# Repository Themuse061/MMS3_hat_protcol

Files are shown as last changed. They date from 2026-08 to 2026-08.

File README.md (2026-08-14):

# MMS3 Hat Protocol
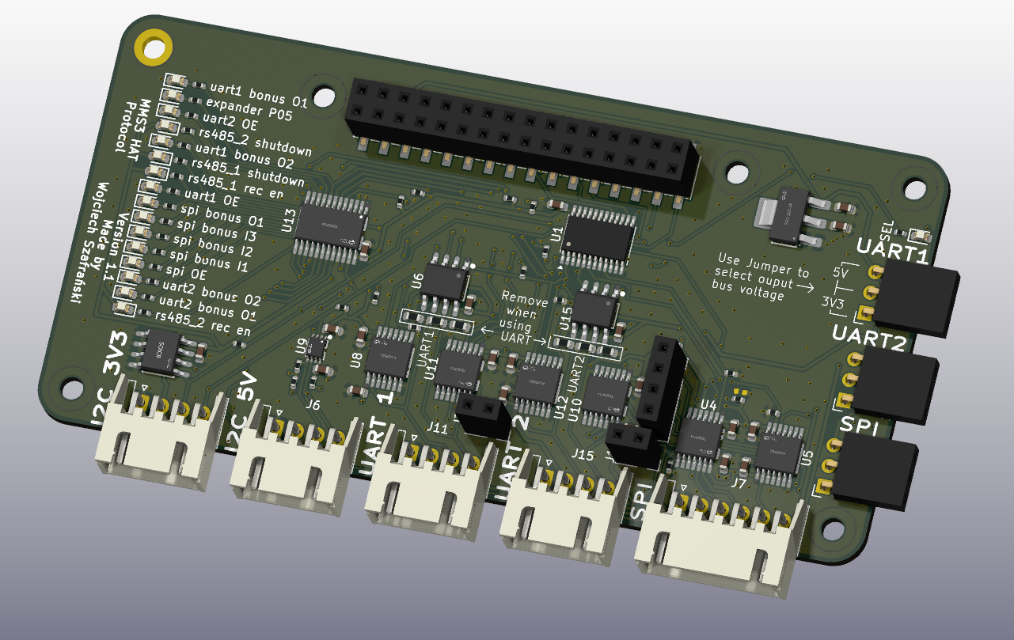
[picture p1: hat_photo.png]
zdjęcie

## Sekcja 1: Dokumentacja Hat'a

### Krótki opis projektu
Moduł rozszerzeń protokołów komunikacyjnych dla standardu ChainBus. Hat umożliwia podłączanie urządzeń zewnętrznych komunikujących się za pomocą interfejsów UART, RS485, I2C oraz SPI.

Umożliwia  zmianę napięć logicznych (3.3V lub 5V) osobno dla każdej sekcji, a linie komunikacyjne są domyślnie odłączone przy starcie systemu.

### Zgodność ze standardem ChainBus

* ✅  Używa złącza ChainBus, nie zmienia jego miejsca ani pinoutu.
* ✅  Używa wyłącznie interfejsów I2C, SPI lub UART i nie inicjuje samodzielnie nowych transmisji (Nie jest master'em I2C albo SPI).
* ✅  Spełnia wymagania mechaniczne standardu (wymiary PCB, rozstaw otworów).
* ✅  Pobiera maksymalny prąd zgodny z ilością na jednego hat'a
* ✅  Obsługuje napięcie wejściowe BRD_VIN do wartości 48V.

### Komunikacja i adresowanie

#### Adresacja I2C
Do konfiguracji pracy buforów trójstanowych oraz transceiverów RS485 wykorzystywany jest ekspander GPIO.

| Układ (IC) | Funkcja | Adres I2C (7-bit) |
| :--- | :--- | :---: |
| **TCA9535PWR** | Ekspander GPIO (sterowanie buforami) | `0100000b` (0x20) |

Uwaga: Adresy expander'a gpio i pamięci EEPROM są zajęte na I2C wychodzącym z hat'a

---

### Konfiguracja i wybór napięć logicznych (3.3V / 5V)

Sekcje UART1, UART2 oraz SPI posiadają niezależną regulację napięcia pracy za pomocą zworek:

| Zworka  | Sekcja | Pozycja 1-2 | Pozycja 2-3 |
| :--- | :----- | :--- | :--- |
| **J8**  | UART 1 | Napięcie logiki **3.3V** | Napięcie logiki **5V** |
| **J14** | UART 2 | Napięcie logiki **3.3V** | Napięcie logiki **5V** |
| **J5**  | SPI | Napięcie logiki **3.3V** | Napięcie logiki **5V** |

---

### Pełny pinout ekspandera GPIO (TCA9535PWR)

Wszystkie magistrale (z wyjątkiem I2C) są przy starcie urządzenia **fizycznie odłączone**. Do ich aktywacji i konfiguracji służą poniższe piny ekspandera:

| Port | Nazwa sygnału | Domyślny stan sprzętowy  | Opis funkcjonalny |
| :--- | :--- | :--- | :--- |
| **P00** | `UART 1 OE` | Niski (L) - Odłączony | Aktywacja (Output Enable) bufora linii UART 1 |
| **P01** | `UART 1 RS485 RE_N` | Wysoki (H)  - Wyłączony  | Negowane wejście Receiver Enable ($\overline{RE}$) dla RS485-1 |
| **P02** | `UART 1 SHDN_N` | Wysoki (H) - Wyłączony | Negowane wejście Shutdown ($\overline{SD}$) dla RS485-1 |
| **P03** | `UART 1 BONUS OUT`  | Niski (L) | Dodatkowe wyjście pomocnicze (Bonus Out) na złączu J12 |
| **P04** | `UART 1 BONUS OUT`  | Niski (L) | Dodatkowe wyjście pomocnicze (Bonus Out) na złączu J12 |
| **P05** | `STATUS LED` | - | Dioda statusowa ogólnego przeznaczenia (LED) |
| **P06** | `UART 2 OE` | Niski (L) - Odłączony | Aktywacja (Output Enable) bufora linii UART 2 |
| **P07** | `UART 2 RS485 RE_N` | Wysoki (H) - Wyłączony | Negowane wejście Receiver Enable ($\overline{RE}$) dla RS485-2 |
| **P10** | `UART 2 SHDN_N` | Wysoki (H) - Wyłączony | Negowane wejście Shutdown ($\overline{SD}$) dla RS485-2 |
| **P11** | `UART 2 BONUS OUT`  | Niski (L) | Dodatkowe wyjście pomocnicze (Bonus Out) na złączu J13 |
| **P12** | `UART 2 BONUS OUT`  | Niski (L) | Dodatkowe wyjście pomocnicze (Bonus Out) na złączu J13 |
| **P13** | `SPI 1 ENABLE` | Niski (L) - Odłączony | Aktywacja (Output Enable) bufora linii SPI |
| **P14** | `SPI 1 BONUS IN` | — | Dodatkowe wejście pomocnicze (Bonus In) na złączu J9 |
| **P15** | `SPI 1 BONUS IN` | — | Dodatkowe wejście pomocnicze (Bonus In) na złączu J9 |
| **P16** | `SPI 1 BONUS IN` | — | Dodatkowe wejście pomocnicze (Bonus In) na złączu J9 |
| **P17** | `SPI 1 BONUS OUT` | — | Dodatkowe wyjście pomocnicze (Bonus Out) na złączu J9 |

---

### Konfiguracja trybów pracy: UART vs RS485

Linie komunikacyjne oraz złącza fizyczne są współdzielone pomiędzy standardowym interfejsem UART a różnicowym RS485. Wymaga to odpowiedniej konfiguracji sprzętowej i programowej.

#### Tryb 1: Standardowy UART
Aby używać kanału jako klasycznego interfejsu UART:
1. **Włącz magistralę:** Ustaw odpowiedni pin `UART OE` (P00 lub P06) w stan wysoki (`1`).
2. **Wylutuj rezystor terminujący:** Należy  **odlutować rezystor terminujący RS485** ($120\ \Omega$) przypisany do danego kanału (rezystory są oznaczone  na  PCB). Pozostawienie rezystora obciąży linie RX/TX, co może powodować błędy lub uszkodzenie układu.

#### Tryb 2: Interfejs RS485
Aby używać kanału w standardzie  RS485:
1. **Włącz magistralę:** Ustaw odpowiedni pin `UART OE` (P00 lub P06) w stan wysoki (`1`).
2. **Aktywuj transceiver:** Ustaw piny Receiver Enable (`RE_N`) oraz Shutdown (`SHDN_N`) w stan niski (`0`).
3. **Terminacja linii:** Rezystor terminujący na PCB powinien pozostać wlutowany .

---

### Pinout złączy zewnętrznych

#### J11 (UART1 / RS485-1) oraz J15 (UART2 / RS485-2)
Złącza te współdzielą piny fizyczne dla obu standardów komunikacji.

| Pin | Nazwa | Funkcja w trybie UART | Funkcja w trybie RS485 |
| :---- | :--- | :--- | :--- |
| **1** | `GND` | Masa sygnałowa | Masa odniesienia |
| **2** | `V_SEL`  | Wybrane zasilanie (3.3V / 5V) | Wybrane zasilanie (3.3V / 5V) |
| **3** | `A / RX` | Odbiór danych (RX) | Linia różnicowa **A** (nieodwracająca) |
| **4** | `B / TX` | Nadawanie danych (TX) | Linia różnicowa **B** (odwracająca) |

#### J4 (I2C 3.3V) oraz J6 (I2C 5V)
Złącza magistrali I2C są połączone na stałe do linii ChainBus poprzez odpowiednie translatory poziomów.
* **J4 (3.3V):** Pin 1: GND | Pin 2: 3.3V | Pin 3: SDA 3.3V | Pin 4: SCL 3.3V
* **J6 (5.0V):** Pin 1: GND | Pin 2: 5.0V | Pin 3: SDA 5.0V | Pin 4: SCL 5.0V

#### J7 (SPI)
Złącze magistrali SPI z konwersją napięć (3.3V / 5V w zależności od J5):
* Pin 1: GND | Pin 2: V_SEL | Pin 3: SCK | Pin 4: MOSI | Pin 5: MISO | Pin 6: CS

---

### Złącza pomocnicze (Bonus Pins)

Złącza te służą do wyprowadzenia dodatkowych sygnałów cyfrowych sprzężonych z buforami danej magistrali. Działają tylko wtedy, gdy bufor nadrzędnej magistrali jest włączony (`OE` = `1`).

* **J12 (UART 1):** Pin 1: `P01` (In) | Pin 2: `P02` (Out/In) | Pin 3: `P03` (Out) | Pin 4: `P04` (Out)
* **J13 (UART 2):** Pin 1: `P07` (In) | Pin 2: `P10` (Out/In) | Pin 3: `P11` (Out) | Pin 4: `P12` (Out)
* **J9 (SPI):** Pin 1: `P14` (In) | Pin 2: `P15` (In) | Pin 3: `P16` (In) | Pin 4: `P17` (Out)

---

### Gotowe arkusze hierarchiczne
W projekcie wykorzystano następujące arkusze hierarchiczne:
* **SPI tri state switch** – Moduł przełączania linii interfejsu SPI z użyciem buforów trójstanowych oraz układów konwersji poziomów napięciowych (3.3V <-> 5V).
* **UART tri state switch + RS485 converter** – Blok przełączania linii UART z dopasowaniem poziomów napięć oraz zintegrowanym transceiverem RS485 i układem sterowania przepływem danych (RE/SHDN).

---

## Sekcja 2: Specyfikacja standardu ChainBus

### Architektura i łączenie modułów
Standard ChainBus umożliwia modułowe łączenie hatów. Na jednym MMS3 można zamontować pionowo **do 8 hat'ów**. Połączenie realizowane jest poprzez wpięcie złącza męskiego kolejnego hat'a w złącze żeńskie poprzedniego.

### Komunikacja i sterowanie
Magistrala ChainBus jest w pełni cyfrowa. Płyta główna nie steruje bezpośrednio sygnałami ogólnego przeznaczenia (GPIO) na poszczególnych hat'ach. Wszelkie operacje (np. odczyt czujników, przełączanie magistral) muszą być realizowane przez dedykowane układy scalone komunikujące się przez interfejsy systemowe.

Wybór aktywnego modułu realizowany jest przez układ przełącznika magistrali (bus switch) na płycie głównej. Dzięki temu linie I2C, SPI i UART są niezależne dla każdego hat'a (brak konfliktów adresów I2C między różnymi hatami).
* **Identyfikacja:** Każdy moduł powinien posiadać pamięć EEPROM na magistrali I2C w celu identyfikacji płyty przez system - układ M24C64-W skonfigurowany na adres `1010000` przy liniach adresowych A0, A1, A2 zwartych do masy.

### Zasilanie
Złącze ChainBus dostarcza następujące linie zasilania:

| Magistrala zasilania | Napięcie znamionowe | Maksymalny prąd (łączny dla 8 hatów) | Szacowany prąd na jeden hat |
| :--- | :---: | :---: | :---: |
| **5V** | 5.0 V | 1.0 A | 125 mA |
| **12V stby** | 12.0 V | 0.5 A | 65 mA |
| **BRD_VIN** | 12.0 V – 48.0 V | 1.5 A | 185 mA |

*   Komponenty podłączone do linii `BRD_VIN` muszą być przystosowane do pracy z napięciem od 12V do **48 V**.

### Wymagania mechaniczne i złącza
* **Wymiary PCB:** Niedozwolona jest zmiana obrysu płytki oraz położenia otworów montażowych, aby zachować kompatybilność mechaniczną.
* **Pozycjonowanie złączy ChainBus:** Położenie złącza standardu 2x16 SMD (raster 2.54 mm) musi być zgodne z szablonem. Złącze żeńskie montowane jest na stronie FRONT, natomiast złącze męskie na stronie BACK.
* **Komponenty:** Wszystkie komponenty powinny znajdować się na stronie FRONT płytki, aby uniknąć kolizji mechanicznych z elementami sąsiadujących modułów w stosie.

---

## Sekcja 3: Licencje

### Licencje projektu

*   **PCB:** CERN-OHL-P
*   **Software:** MIT License

[Template](https://github.com/KoNaR-Hefajstos/MMS3_hat_templates/) jest na licencji CC0 1.0 Universal. **Reszta projektu nie jest na tej licencji**

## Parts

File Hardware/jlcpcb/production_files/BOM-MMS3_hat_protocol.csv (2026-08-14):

Comment | Designator | Footprint | LCSC | Quantity
100nF | C1,C10,C11,C12,C13,C14,C15,C17,C18,C19,C2,C20,C21,C22,C4,C6,C7,C8,C9 | C_0603 | C14663 | 19
10kΩ | R10,R11,R15,R16,R17,R18,R19,R2,R20,R22,R3,R38,R40,R42,R44,R6,R8,R9 | R_0402 | C25744 | 18
10uF | C3,C5 | C_0603 | C19702 | 2
120Ω | R25,R28 | R_0603 | C22787 | 2
200kΩ | R7 | R_0402 | C25764 | 1
330Ω | R12,R13,R14,R21,R37,R39,R41,R43,R45,R46,R47,R48,R49,R5,R50,R51,R52 | R_0402 | C25104 | 17
510Ω | R23,R24,R26,R27 | R_0603 | C23193 | 4
AMS1117 | U3 | SOT-223-3_L6.5-W3.4-P2.30-LS7.0-BR | C6186 | 1
M24C64 | U2 | SOIC-8_L5.0-W4.0-P1.27-LS6.0-BL | C79988 | 1
MAX13487EESA | U15,U6 | SOIC-8_L4.9-W3.9-P1.27-LS6.0-BL | C18347 | 2
PCA9306DCUR | U9 | SSOP-8_L2.0-W2.3-P0.50-LS3.1-BR | C33196 | 1
Red | D10,D15,D16,D17,D18,D19,D20,D21,D22,D23,D24,D25,D26,D6,D7,D8,D9 | D_0603 | C2286 | 17
SN74CB3Q3384APW | U1 | TSSOP-24_4.4x7.8mm_P0.65mm | C469874 | 1
TCA9535PWR_C130204 | U13 | TSSOP-24_L7.8-W4.4-P0.65-LS6.4-BL | C130204 | 1
TXU0104PWR | U10,U11,U12,U4,U5,U8 | TSSOP-14_L5.0-W4.4-P0.65-LS6.4-BL | C2938871 | 6
Conn_01x02_Pin | J10 | PinSocket_1x02_P2.54mm_Vertical |  | 1
Conn_01x04_Pin | J9 | PinSocket_1x04_P2.54mm_Vertical |  | 1
Chainbus Out | J2 | PinSocket_2x16_P2.54mm_Vertical_SMD |  | 1
Conn_01x03_Pin | J5 | PinSocket_1x03_P2.54mm_Horizontal |  | 1
Conn_01x02_Pin | J3 | PinSocket_1x02_P2.54mm_Vertical |  | 1
Conn_01x04_Pin | J15 | JST_XH_S4B-XH-A_1x04_P2.50mm_Horizontal |  | 1
Conn_01x03_Pin | J14 | PinSocket_1x03_P2.54mm_Horizontal |  | 1
Conn_01x04_Pin | J11 | JST_XH_S4B-XH-A_1x04_P2.50mm_Horizontal |  | 1
Conn_01x03_Pin | J8 | PinSocket_1x03_P2.54mm_Horizontal |  | 1
Conn_01x04_Pin | J4 | JST_XH_S4B-XH-A_1x04_P2.50mm_Horizontal |  | 1
Conn_01x06_Pin | J7 | JST_XH_S6B-XH-A_1x06_P2.50mm_Horizontal |  | 1
Conn_01x04_Pin | J6 | JST_XH_S4B-XH-A_1x04_P2.50mm_Horizontal |  | 1
Chainbus in | J1 | PinHeader_2x16_P2.54mm_Vertical_SMD |  | 1

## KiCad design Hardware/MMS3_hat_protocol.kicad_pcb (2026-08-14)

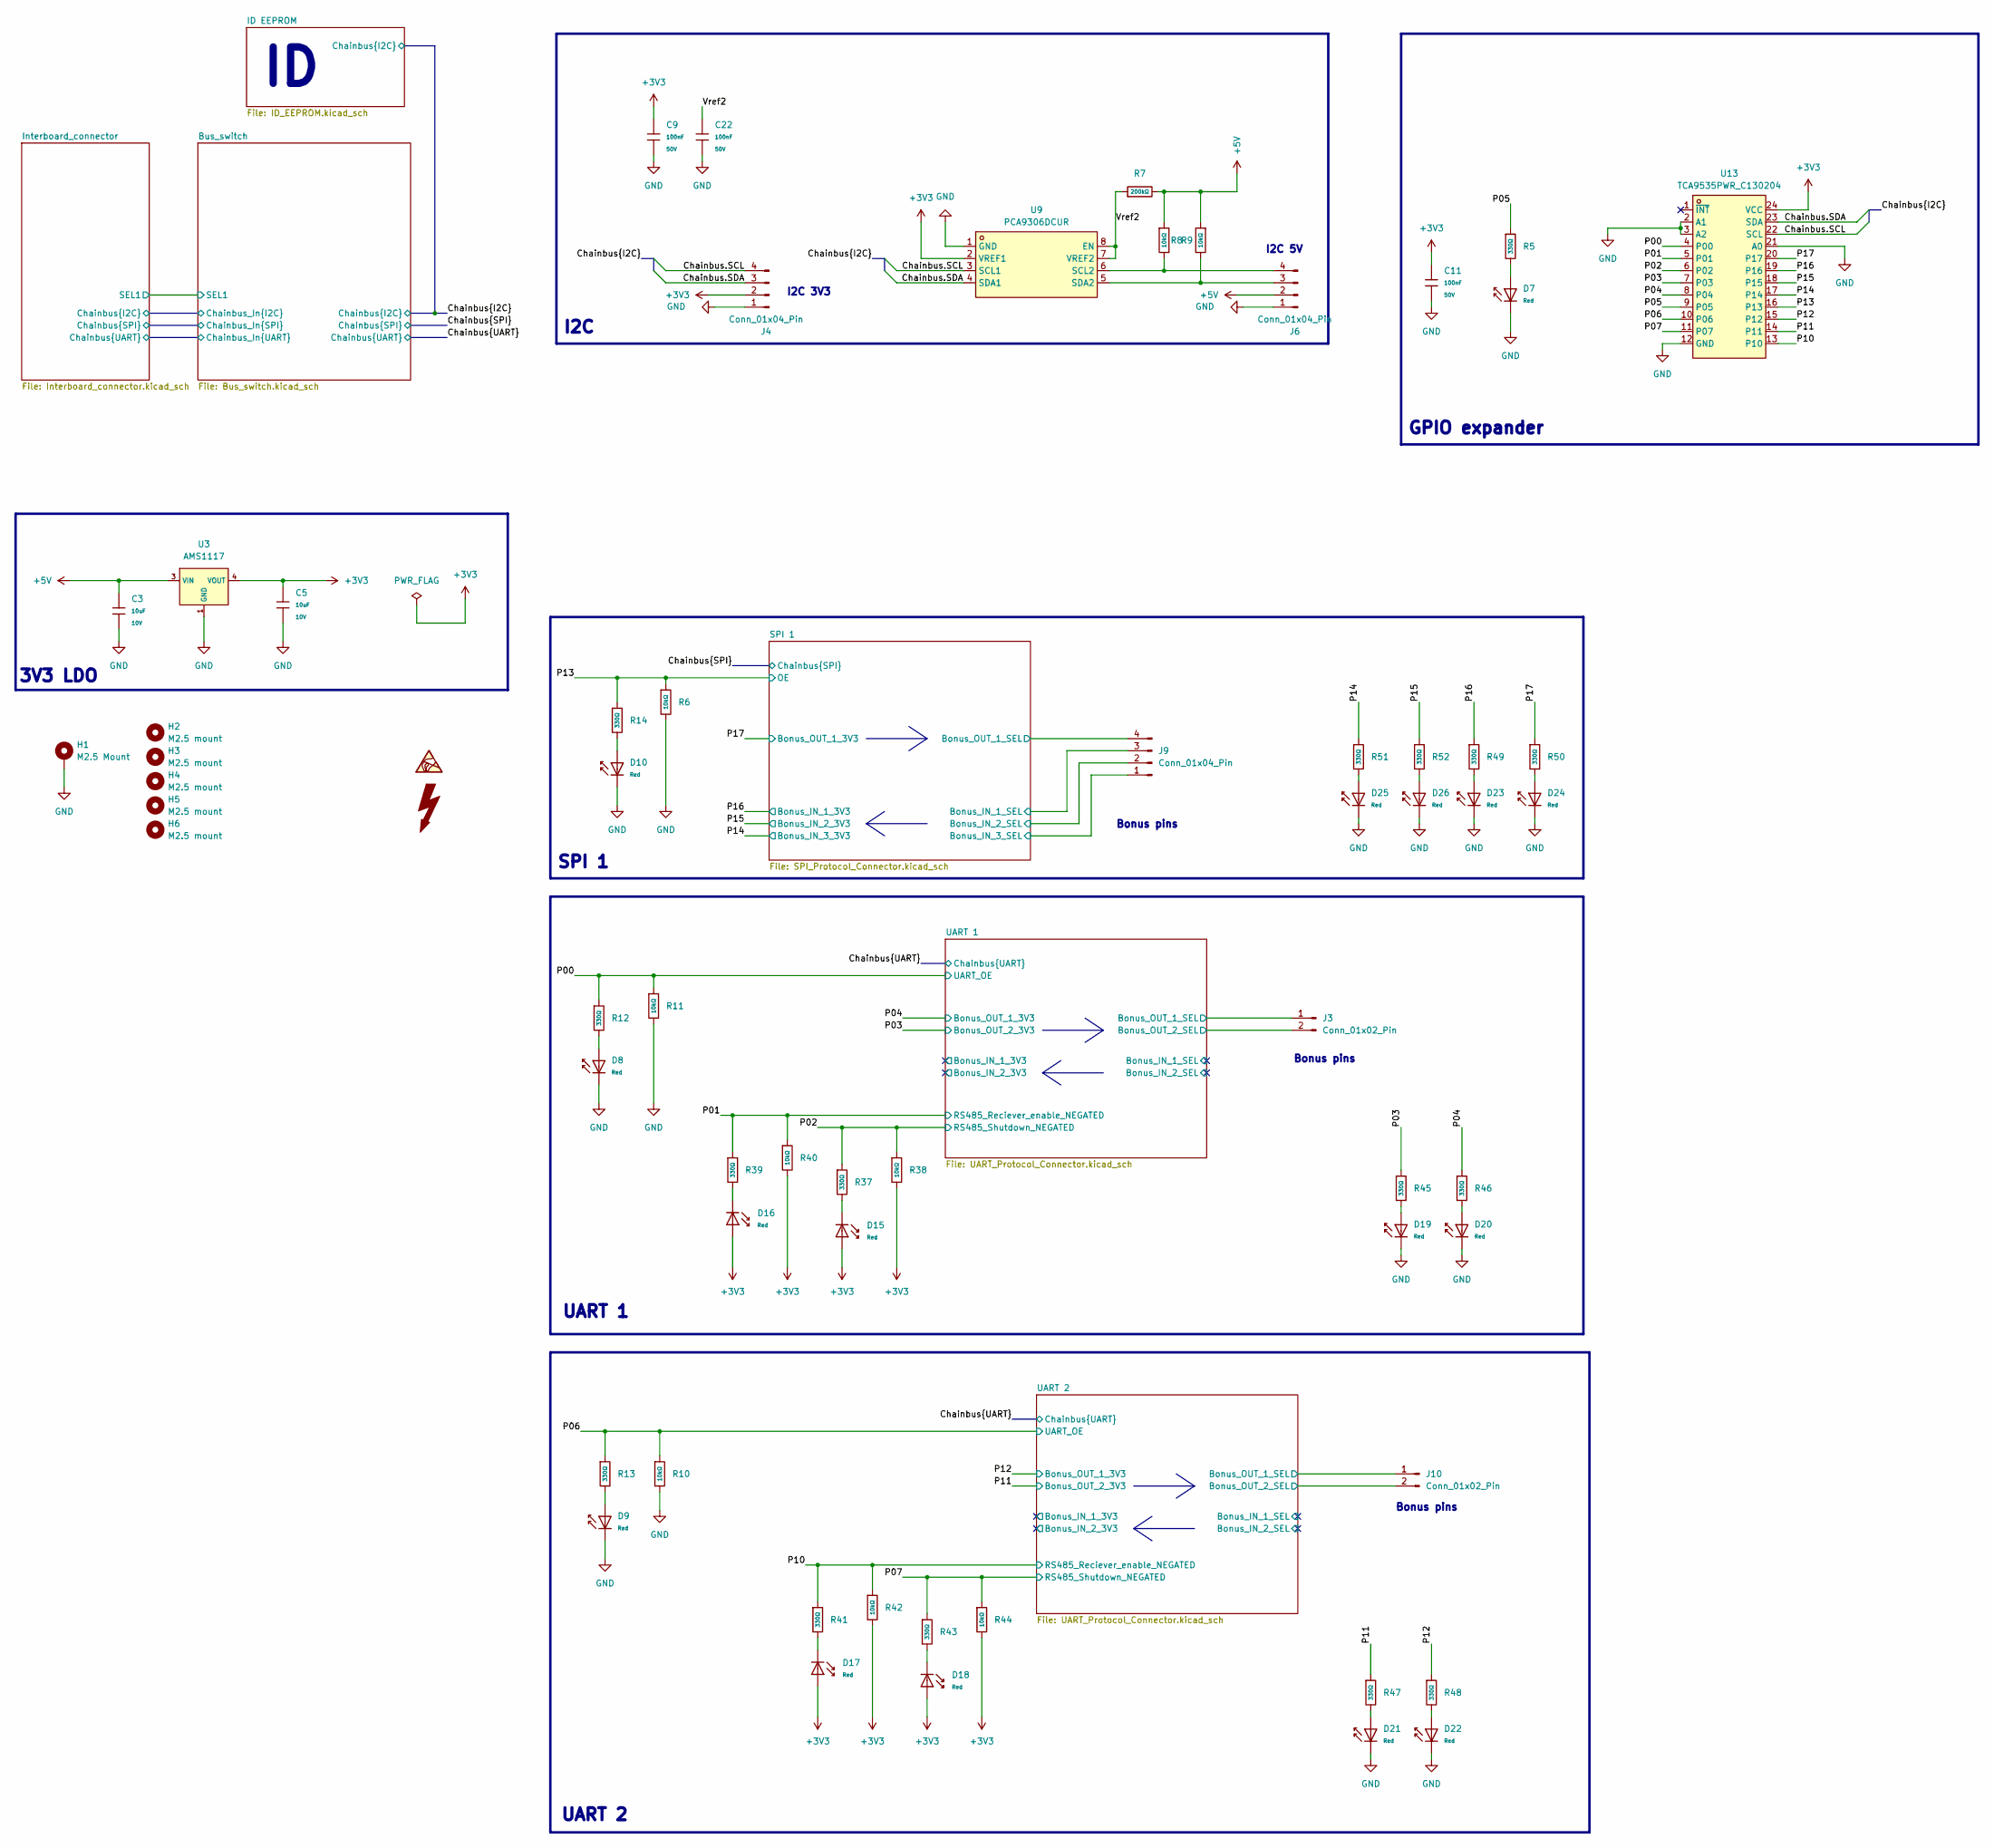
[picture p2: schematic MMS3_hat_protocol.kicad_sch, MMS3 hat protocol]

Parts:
C3, C5: 10uF; C_0603; Voltage Rated 10V; Tolerance ±10%; Part CL10A106KP8NNNC; LCSC C19702
C9, C11, C22: 100nF; C_0603; Voltage Rated 50V; Tolerance ±10%; Part CC0603KRX7R9BB104; LCSC C14663
D7, D8, D9, D10, D15, D16, D17, D18, D19, D20, D21, D22, D23, D24, D25, D26: Red; D_0603; Part KT-0603R; LCSC C2286
H1: M2.5 Mount; MountingHole_2.7mm_M2.5_DIN965_Pad_TopOnly
H2, H3, H4, H5, H6: M2.5 mount; MountingHole_2.7mm_M2.5
J3, J10: Conn_01x02_Pin; PinSocket_1x02_P2.54mm_Vertical
J4, J6: Conn_01x04_Pin; JST_XH_S4B-XH-A_1x04_P2.50mm_Horizontal
J9: Conn_01x04_Pin; PinSocket_1x04_P2.54mm_Vertical
R5, R12, R13, R14, R37, R39, R41, R43, R45, R46, R47, R48, R49, R50, R51, R52: 330Ω; R_0402; Overload Voltage (Max) 50V; Tolerance ±1%; Part 0402WGF3300TCE; LCSC C25104
R6, R8, R9, R10, R11, R38, R40, R42, R44: 10kΩ; R_0402; Overload Voltage (Max) 50V; Tolerance ±1%; Part 0402WGF1002TCE; LCSC C25744
R7: 200kΩ; R_0402; Overload Voltage (Max) 50V; Tolerance ±1%; Part 0402WGF2003TCE; LCSC C25764
U3: AMS1117; SOT-223-3_L6.5-W3.4-P2.30-LS7.0-BR; Output Voltage 3.3V; Dropout Voltage 1.3V@(800mA); Part AMS1117-3.3; LCSC C6186
U9: PCA9306DCUR; SSOP-8_L2.0-W2.3-P0.50-LS3.1-BR; MPN PCA9306DCUR; LCSC Part C33196
U13: TCA9535PWR_C130204; TSSOP-24_L7.8-W4.4-P0.65-LS6.4-BL; MPN TCA9535PWR; LCSC Part C130204

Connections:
+3V3: C5.1, C9.1, C11.1, D15.2, D16.2, D17.2, D18.2, J4.2, R38.2, R40.2, R42.2, R44.2, U3.2 (VOUT), U3.4 (VOUT), U9.2 (VREF1), U13.24 (VCC); also elsewhere on the board
+5V: C3.1, J6.2, R7.2, R8.1, R9.1, U3.3 (VIN); also elsewhere on the board
/Chainbus.SCL: J4.4, U9.3 (SCL1), U13.22 (SCL); also elsewhere on the board
/Chainbus.SDA: J4.3, U9.4 (SDA1), U13.23 (SDA); also elsewhere on the board
/P00: R11.1, R12.1, U13.4 (P00); also elsewhere on the board
/P01: R39.1, R40.1, U13.5 (P01); also elsewhere on the board
/P02: R37.1, R38.1, U13.6 (P02); also elsewhere on the board
/P03: R45.1, U13.7 (P03); also elsewhere on the board
/P04: R46.1, U13.8 (P04); also elsewhere on the board
/P05: R5.1, U13.9 (P05)
/P06: R10.1, R13.1, U13.10 (P06); also elsewhere on the board
/P07: R43.1, R44.1, U13.11 (P07); also elsewhere on the board
/P10: R41.1, R42.1, U13.13 (P10); also elsewhere on the board
/P11: R47.1, U13.14 (P11); also elsewhere on the board
/P12: R48.1, U13.15 (P12); also elsewhere on the board
/P13: R6.1, R14.1, U13.16 (P13); also elsewhere on the board
/P14: R51.1, U13.17 (P14); also elsewhere on the board
/P15: R52.1, U13.18 (P15); also elsewhere on the board
/P16: R49.1, U13.19 (P16); also elsewhere on the board
/P17: R50.1, U13.20 (P17); also elsewhere on the board
/SPI 1/Bonus_IN_1_SEL: J9.3; also elsewhere on the board
/SPI 1/Bonus_IN_2_SEL: J9.2; also elsewhere on the board
/SPI 1/Bonus_IN_3_SEL: J9.1; also elsewhere on the board
/SPI 1/Bonus_OUT_1_SEL: J9.4; also elsewhere on the board
/UART 1/Bonus_OUT_1_SEL: J3.1; also elsewhere on the board
/UART 1/Bonus_OUT_2_SEL: J3.2; also elsewhere on the board
/UART 2/Bonus_OUT_1_SEL: J10.1; also elsewhere on the board
/UART 2/Bonus_OUT_2_SEL: J10.2; also elsewhere on the board
/Vref2: C22.1, R7.1, U9.7 (VREF2), U9.8 (EN)
GND: C3.2, C5.2, C9.2, C11.2, C22.2, D7.1, D8.1, D9.1, D10.1, D19.1, D20.1, D21.1, D22.1, D23.1, D24.1, D25.1, D26.1, H1.1 (1_1), J4.1, J6.1, R6.2, R10.2, R11.2, U3.1 (GND), U9.1 (GND), U13.2 (A1), U13.3 (A2), U13.12 (GND), U13.21 (A0); also elsewhere on the board
unnamed: D7.2, R5.2
unnamed: D8.2, R12.2
unnamed: D9.2, R13.2
unnamed: D10.2, R14.2
unnamed: D15.1, R37.2
unnamed: D16.1, R39.2
unnamed: D17.1, R41.2
unnamed: D18.1, R43.2
unnamed: D19.2, R45.2
unnamed: D20.2, R46.2
unnamed: D21.2, R47.2
unnamed: D22.2, R48.2
unnamed: D23.2, R49.2
unnamed: D24.2, R50.2
unnamed: D25.2, R51.2
unnamed: D26.2, R52.2
unnamed: J6.3, R9.2, U9.5 (SDA2)
unnamed: J6.4, R8.2, U9.6 (SCL2)

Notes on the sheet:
I2C 3V3
GPIO expander
Bonus pins
UART 1
I2C 5V
3V3 LDO
I2C
SPI 1
UART 2

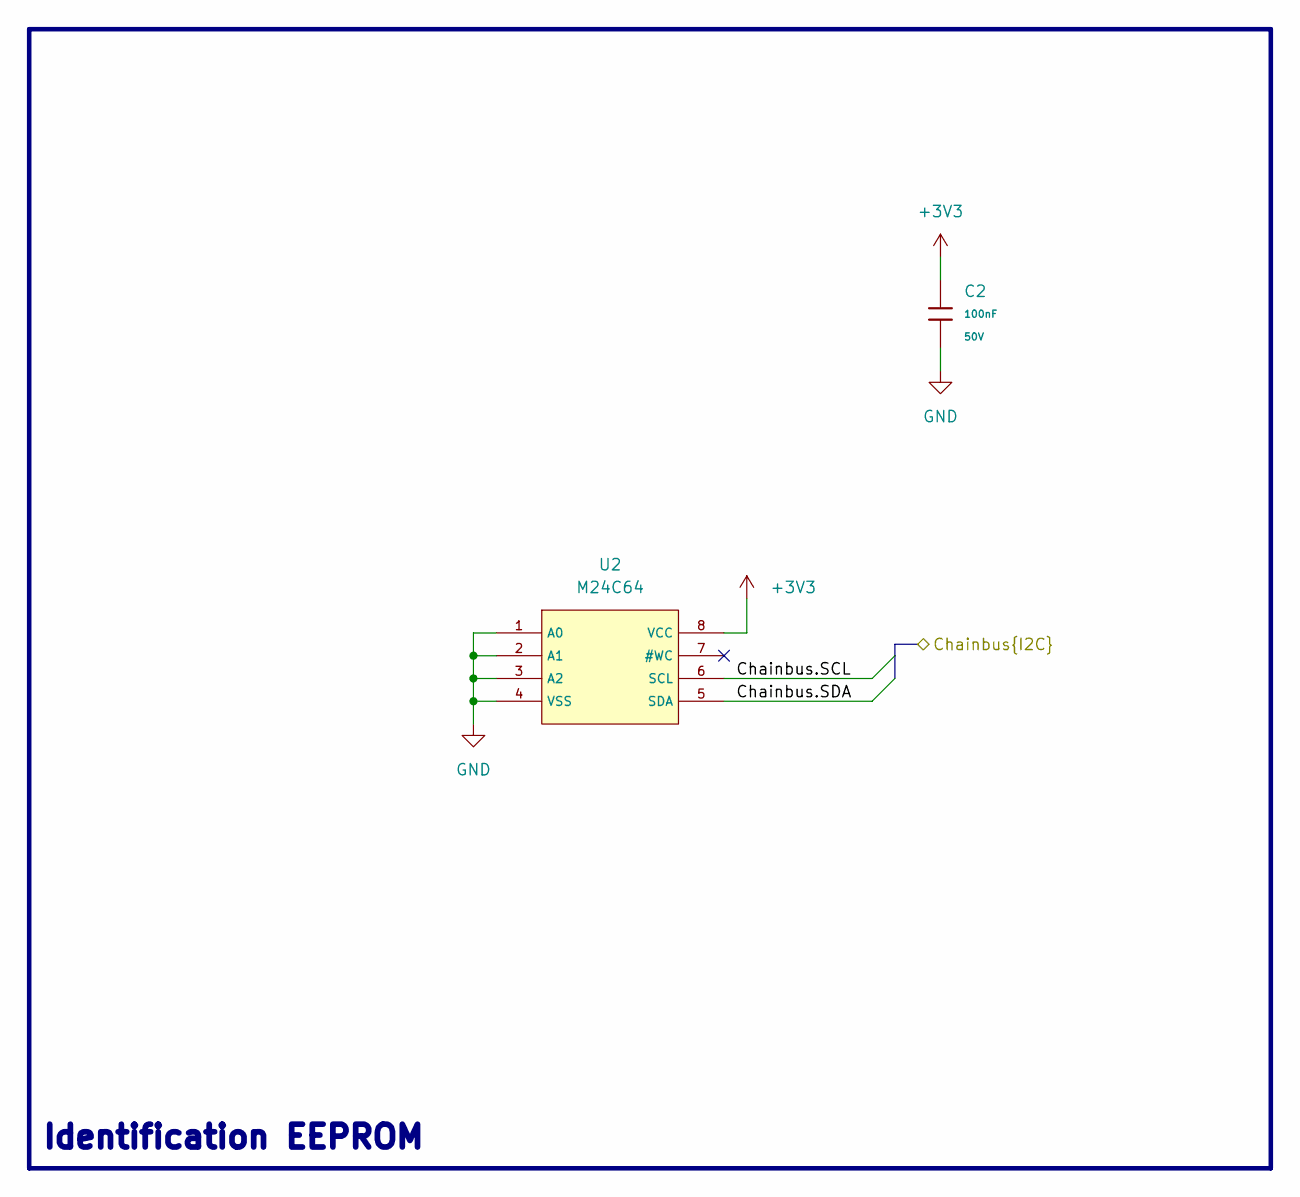
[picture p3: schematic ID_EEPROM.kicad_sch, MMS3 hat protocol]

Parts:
C2: 100nF; C_0603; Voltage Rated 50V; Tolerance ±10%; Part CC0603KRX7R9BB104; LCSC C14663
U2: M24C64; SOIC-8_L5.0-W4.0-P1.27-LS6.0-BL; Supply Voltage 1.8V~5.5V; Part M24C64-RMN6TP; LCSC C79988

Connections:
+3V3: C2.1, U2.8 (VCC); also elsewhere on the board
/Chainbus.SCL: U2.6 (SCL); also elsewhere on the board
/Chainbus.SDA: U2.5 (SDA); also elsewhere on the board
GND: C2.2, U2.1 (A0), U2.2 (A1), U2.3 (A2), U2.4 (VSS); also elsewhere on the board

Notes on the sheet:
Identification EEPROM

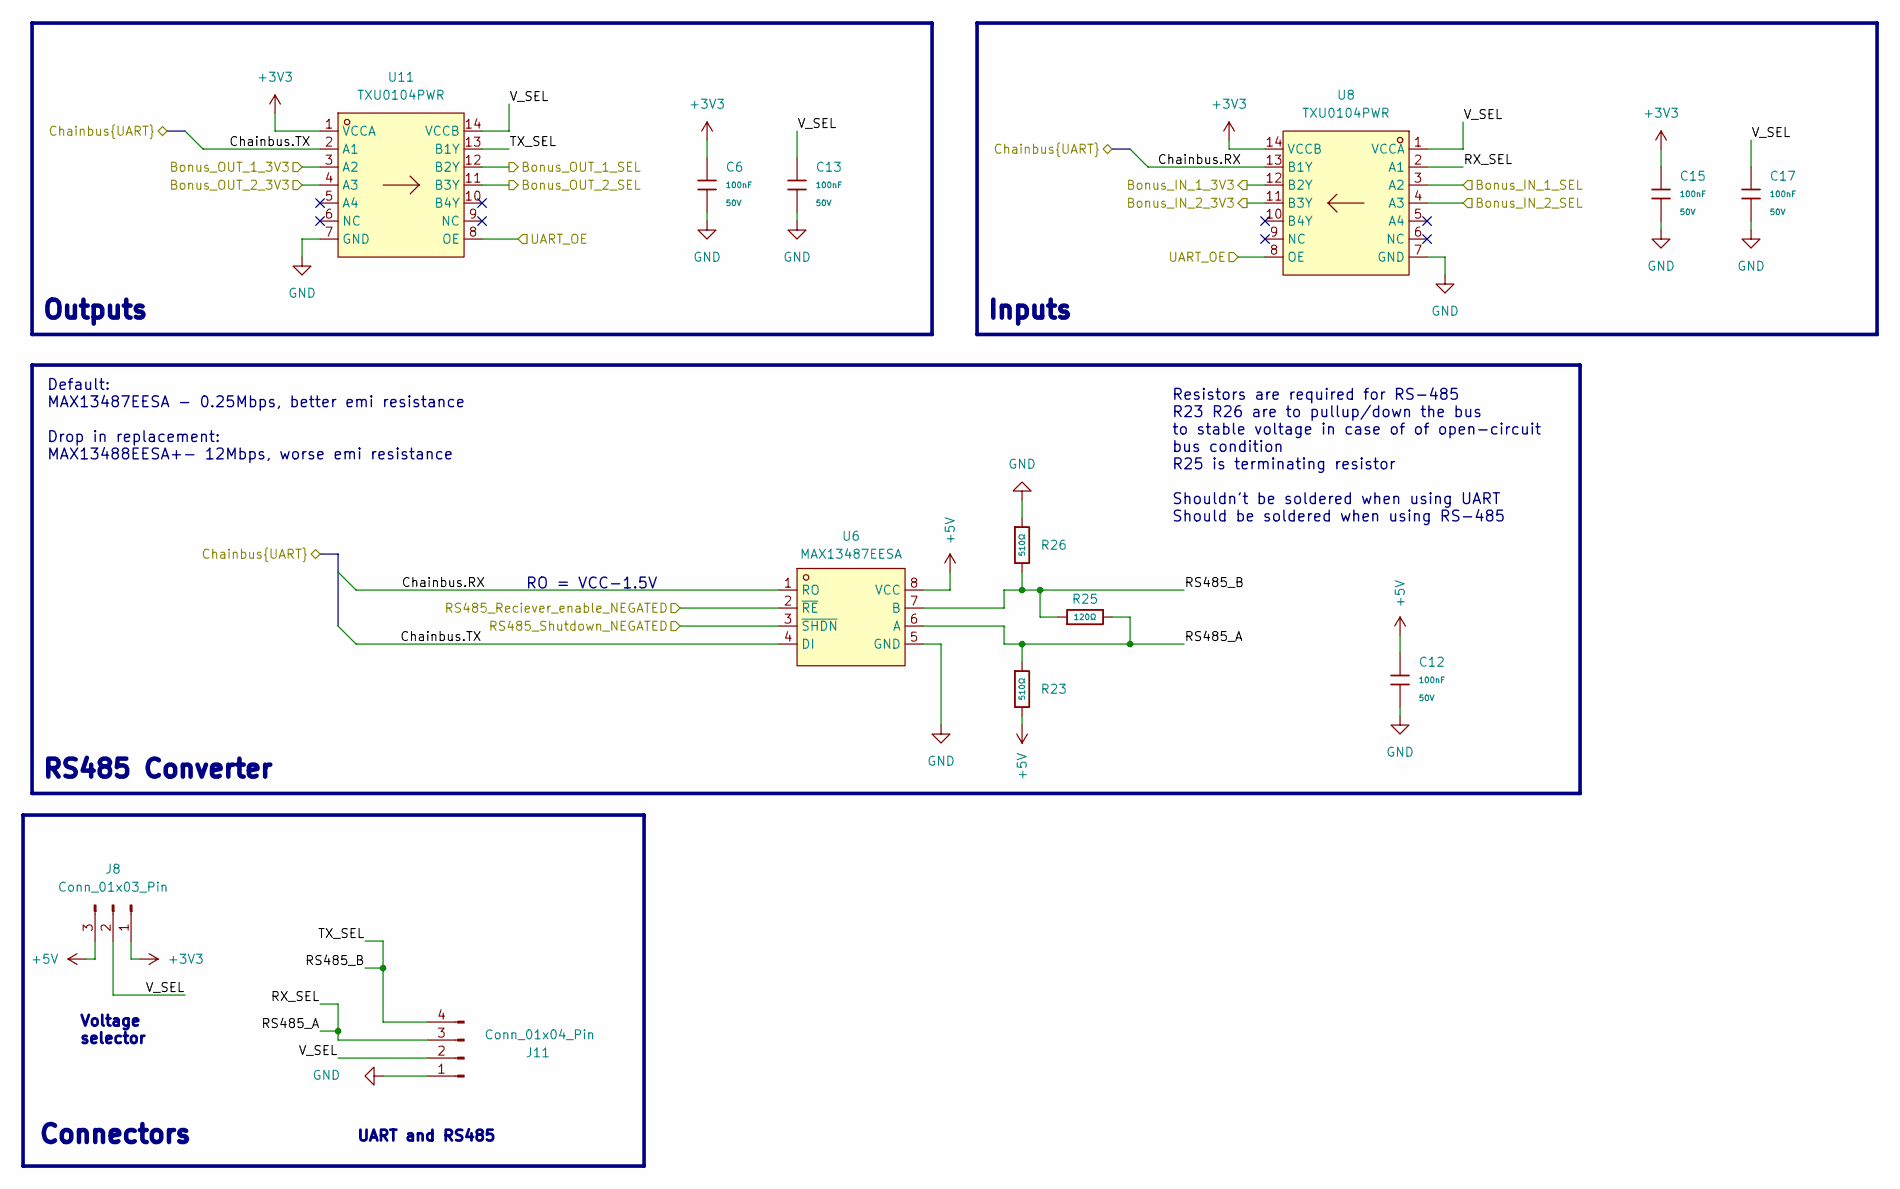
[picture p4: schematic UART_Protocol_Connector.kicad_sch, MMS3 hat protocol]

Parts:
C6, C12, C13, C15, C17: 100nF; C_0603; Voltage Rated 50V; Tolerance ±10%; Part CC0603KRX7R9BB104; LCSC C14663
J8: Conn_01x03_Pin; PinSocket_1x03_P2.54mm_Horizontal
J11: Conn_01x04_Pin; JST_XH_S4B-XH-A_1x04_P2.50mm_Horizontal
R23, R26: 510Ω; R_0603; Overload Voltage (Max) 75V; Tolerance ±1%; Part 0603WAF5100T5E; LCSC C23193
R25: 120Ω; R_0603; Overload Voltage (Max) 75V; Tolerance ±1%; Part 0603WAF1200T5E; LCSC C22787
U6: MAX13487EESA; SOIC-8_L4.9-W3.9-P1.27-LS6.0-BL; MPN MAX13487EESA+T; LCSC Part C18347
U8, U11: TXU0104PWR; TSSOP-14_L5.0-W4.4-P0.65-LS6.4-BL; LCSC Part C2938871

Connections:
+3V3: C6.1, C15.1, J8.1, U8.14 (VCCB), U11.1 (VCCA); also elsewhere on the board
+5V: C12.1, J8.3, R23.2, U6.8 (VCC); also elsewhere on the board
/Chainbus.RX: U6.1 (RO), U8.13 (B1Y); also elsewhere on the board
/Chainbus.TX: U6.4 (DI), U11.2 (A1); also elsewhere on the board
/P00: U8.8 (OE), U11.8 (OE); also elsewhere on the board
/P01: U6.2 (~RE); also elsewhere on the board
/P02: U6.3 (~SHDN); also elsewhere on the board
/P03: U11.4 (A3); also elsewhere on the board
/P04: U11.3 (A2); also elsewhere on the board
/UART 1/Bonus_IN_1_3V3: U8.12 (B2Y)
/UART 1/Bonus_IN_1_SEL: U8.3 (A2)
/UART 1/Bonus_IN_2_3V3: U8.11 (B3Y)
/UART 1/Bonus_IN_2_SEL: U8.4 (A3)
/UART 1/Bonus_OUT_1_SEL: U11.12 (B2Y); also elsewhere on the board
/UART 1/Bonus_OUT_2_SEL: U11.11 (B3Y); also elsewhere on the board
/UART 1/RS485_A: J11.3, R23.1, R25.2, U6.6 (A), U8.2 (A1)
/UART 1/RS485_B: J11.4, R25.1, R26.2, U6.7 (B), U11.13 (B1Y)
/UART 1/V_SEL: C13.1, C17.1, J8.2, J11.2, U8.1 (VCCA), U11.14 (VCCB)
GND: C6.2, C12.2, C13.2, C15.2, C17.2, J11.1, R26.1, U6.5 (GND), U8.7 (GND), U11.7 (GND); also elsewhere on the board

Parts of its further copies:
C14, C18, C19, C20, C21: 100nF; C_0603; Voltage Rated 50V; Tolerance ±10%; Part CC0603KRX7R9BB104; LCSC C14663
J14: Conn_01x03_Pin; PinSocket_1x03_P2.54mm_Horizontal
J15: Conn_01x04_Pin; JST_XH_S4B-XH-A_1x04_P2.50mm_Horizontal
R24, R27: 510Ω; R_0603; Overload Voltage (Max) 75V; Tolerance ±1%; Part 0603WAF5100T5E; LCSC C23193
R28: 120Ω; R_0603; Overload Voltage (Max) 75V; Tolerance ±1%; Part 0603WAF1200T5E; LCSC C22787
U10, U12: TXU0104PWR; TSSOP-14_L5.0-W4.4-P0.65-LS6.4-BL; LCSC Part C2938871
U15: MAX13487EESA; SOIC-8_L4.9-W3.9-P1.27-LS6.0-BL; MPN MAX13487EESA+T; LCSC Part C18347

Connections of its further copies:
+3V3: C18.1, C20.1, J14.1, U10.1 (VCCA), U12.14 (VCCB); also elsewhere on the board
+5V: C14.1, J14.3, R24.2, U15.8 (VCC); also elsewhere on the board
/Chainbus.RX: U12.13 (B1Y), U15.1 (RO); also elsewhere on the board
/Chainbus.TX: U10.2 (A1), U15.4 (DI); also elsewhere on the board
/P06: U10.8 (OE), U12.8 (OE); also elsewhere on the board
/P07: U15.3 (~SHDN); also elsewhere on the board
/P10: U15.2 (~RE); also elsewhere on the board
/P11: U10.4 (A3); also elsewhere on the board
/P12: U10.3 (A2); also elsewhere on the board
/UART 2/Bonus_IN_1_3V3: U12.12 (B2Y)
/UART 2/Bonus_IN_1_SEL: U12.3 (A2)
/UART 2/Bonus_IN_2_3V3: U12.11 (B3Y)
/UART 2/Bonus_IN_2_SEL: U12.4 (A3)
/UART 2/Bonus_OUT_1_SEL: U10.12 (B2Y); also elsewhere on the board
/UART 2/Bonus_OUT_2_SEL: U10.11 (B3Y); also elsewhere on the board
/UART 2/RS485_A: J15.3, R24.1, R28.2, U12.2 (A1), U15.6 (A)
/UART 2/RS485_B: J15.4, R27.2, R28.1, U10.13 (B1Y), U15.7 (B)
/UART 2/V_SEL: C19.1, C21.1, J14.2, J15.2, U10.14 (VCCB), U12.1 (VCCA)
GND: C14.2, C18.2, C19.2, C20.2, C21.2, J15.1, R27.1, U10.7 (GND), U12.7 (GND), U15.5 (GND); also elsewhere on the board

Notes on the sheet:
Connectors
Voltage selector
UART and RS485
Default: MAX13487EESA - 0.25Mbps, better emi resistance Drop in replacement: MAX13488EESA+- 12Mbps, worse emi resistance
Inputs
RO = VCC-1.5V
Resistors are required for RS-485 R23 R26 are to pullup/down the bus to stable voltage in case of of open-circuit bus condition R25 is terminating resistor Shouldn't be soldered when using UART Should be soldered when using RS-485
RS485 Converter
Outputs

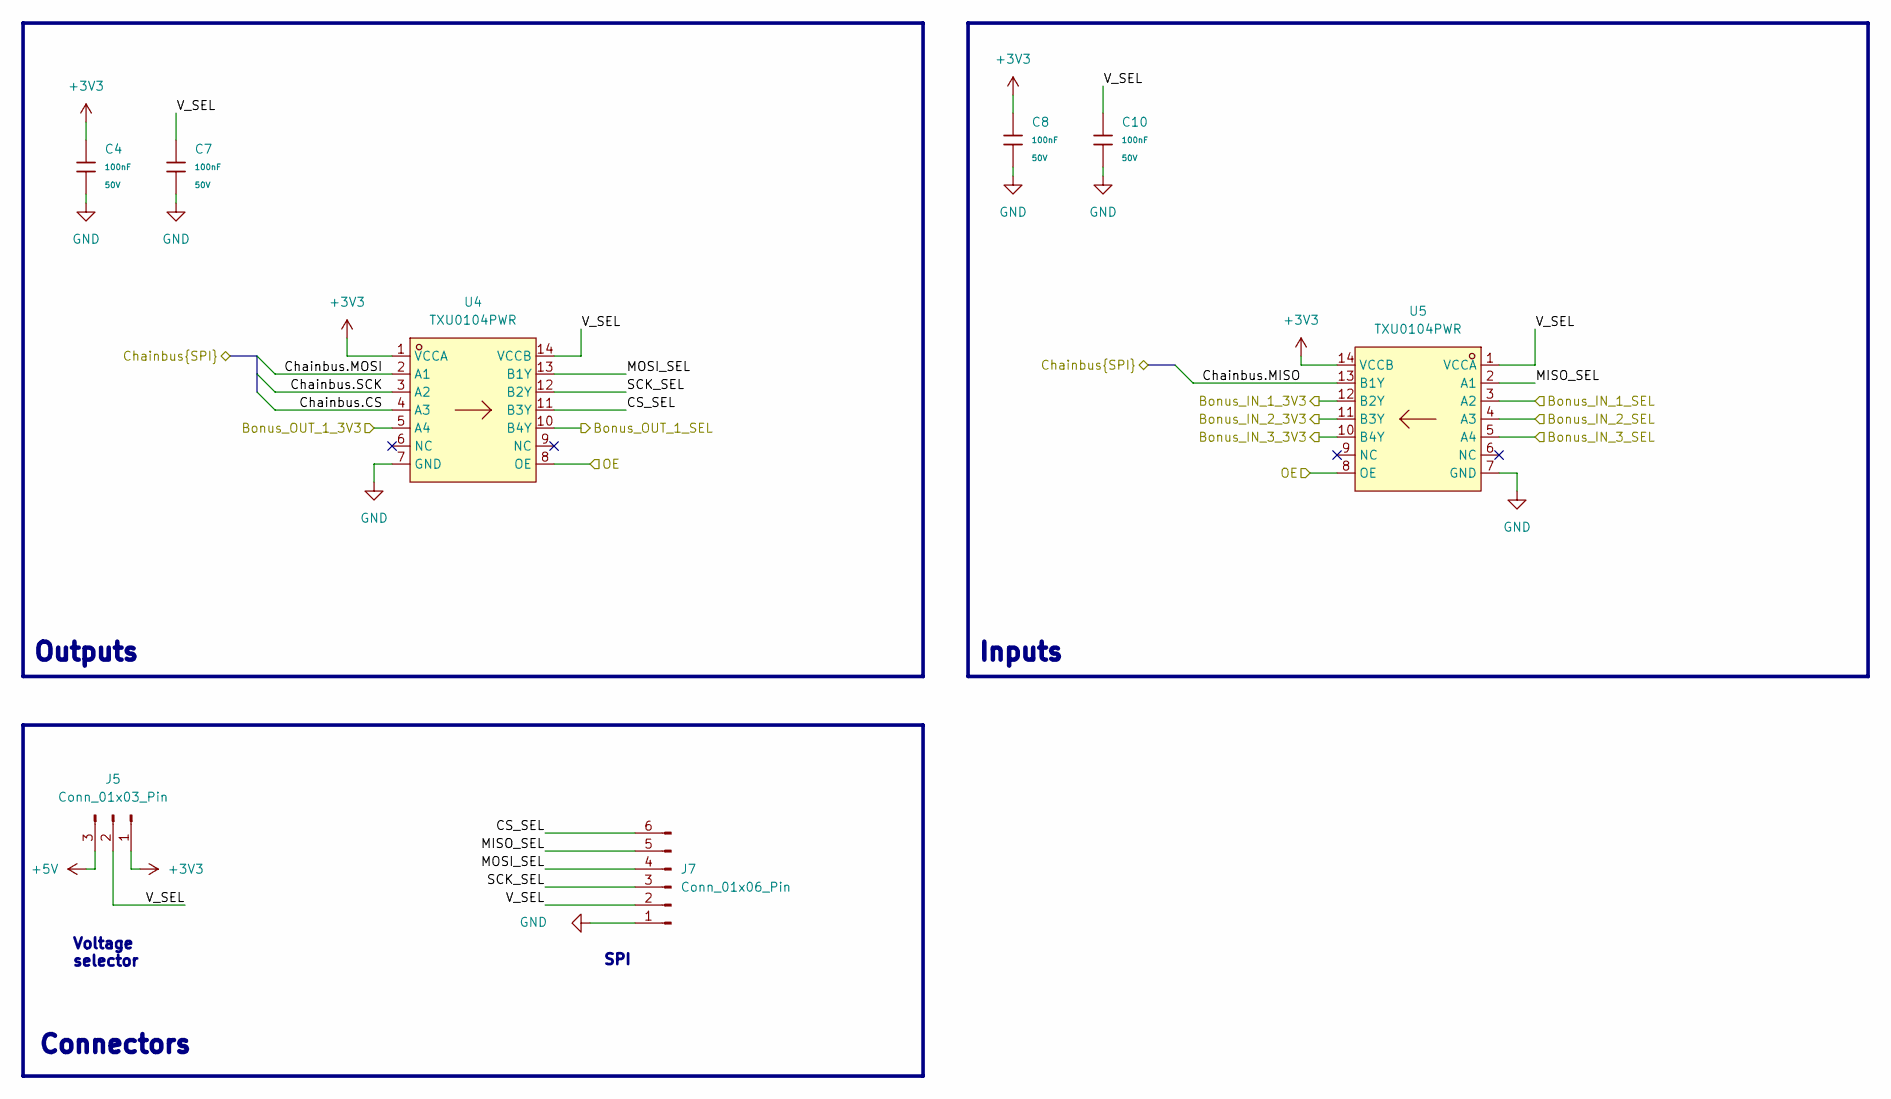
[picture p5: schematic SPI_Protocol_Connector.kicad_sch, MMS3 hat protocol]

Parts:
C4, C7, C8, C10: 100nF; C_0603; Voltage Rated 50V; Tolerance ±10%; Part CC0603KRX7R9BB104; LCSC C14663
J5: Conn_01x03_Pin; PinSocket_1x03_P2.54mm_Horizontal
J7: Conn_01x06_Pin; JST_XH_S6B-XH-A_1x06_P2.50mm_Horizontal
U4, U5: TXU0104PWR; TSSOP-14_L5.0-W4.4-P0.65-LS6.4-BL; LCSC Part C2938871

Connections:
+3V3: C4.1, C8.1, J5.1, U4.1 (VCCA), U5.14 (VCCB); also elsewhere on the board
+5V: J5.3; also elsewhere on the board
/Chainbus.CS: U4.4 (A3); also elsewhere on the board
/Chainbus.MISO: U5.13 (B1Y); also elsewhere on the board
/Chainbus.MOSI: U4.2 (A1); also elsewhere on the board
/Chainbus.SCK: U4.3 (A2); also elsewhere on the board
/P13: U4.8 (OE), U5.8 (OE); also elsewhere on the board
/P14: U5.10 (B4Y); also elsewhere on the board
/P15: U5.11 (B3Y); also elsewhere on the board
/P16: U5.12 (B2Y); also elsewhere on the board
/P17: U4.5 (A4); also elsewhere on the board
/SPI 1/Bonus_IN_1_SEL: U5.3 (A2); also elsewhere on the board
/SPI 1/Bonus_IN_2_SEL: U5.4 (A3); also elsewhere on the board
/SPI 1/Bonus_IN_3_SEL: U5.5 (A4); also elsewhere on the board
/SPI 1/Bonus_OUT_1_SEL: U4.10 (B4Y); also elsewhere on the board
/SPI 1/CS_SEL: J7.6, U4.11 (B3Y)
/SPI 1/MISO_SEL: J7.5, U5.2 (A1)
/SPI 1/MOSI_SEL: J7.4, U4.13 (B1Y)
/SPI 1/SCK_SEL: J7.3, U4.12 (B2Y)
/SPI 1/V_SEL: C7.1, C10.1, J5.2, J7.2, U4.14 (VCCB), U5.1 (VCCA)
GND: C4.2, C7.2, C8.2, C10.2, J7.1, U4.7 (GND), U5.7 (GND); also elsewhere on the board

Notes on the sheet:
Inputs
SPI
Connectors
Outputs
Voltage selector

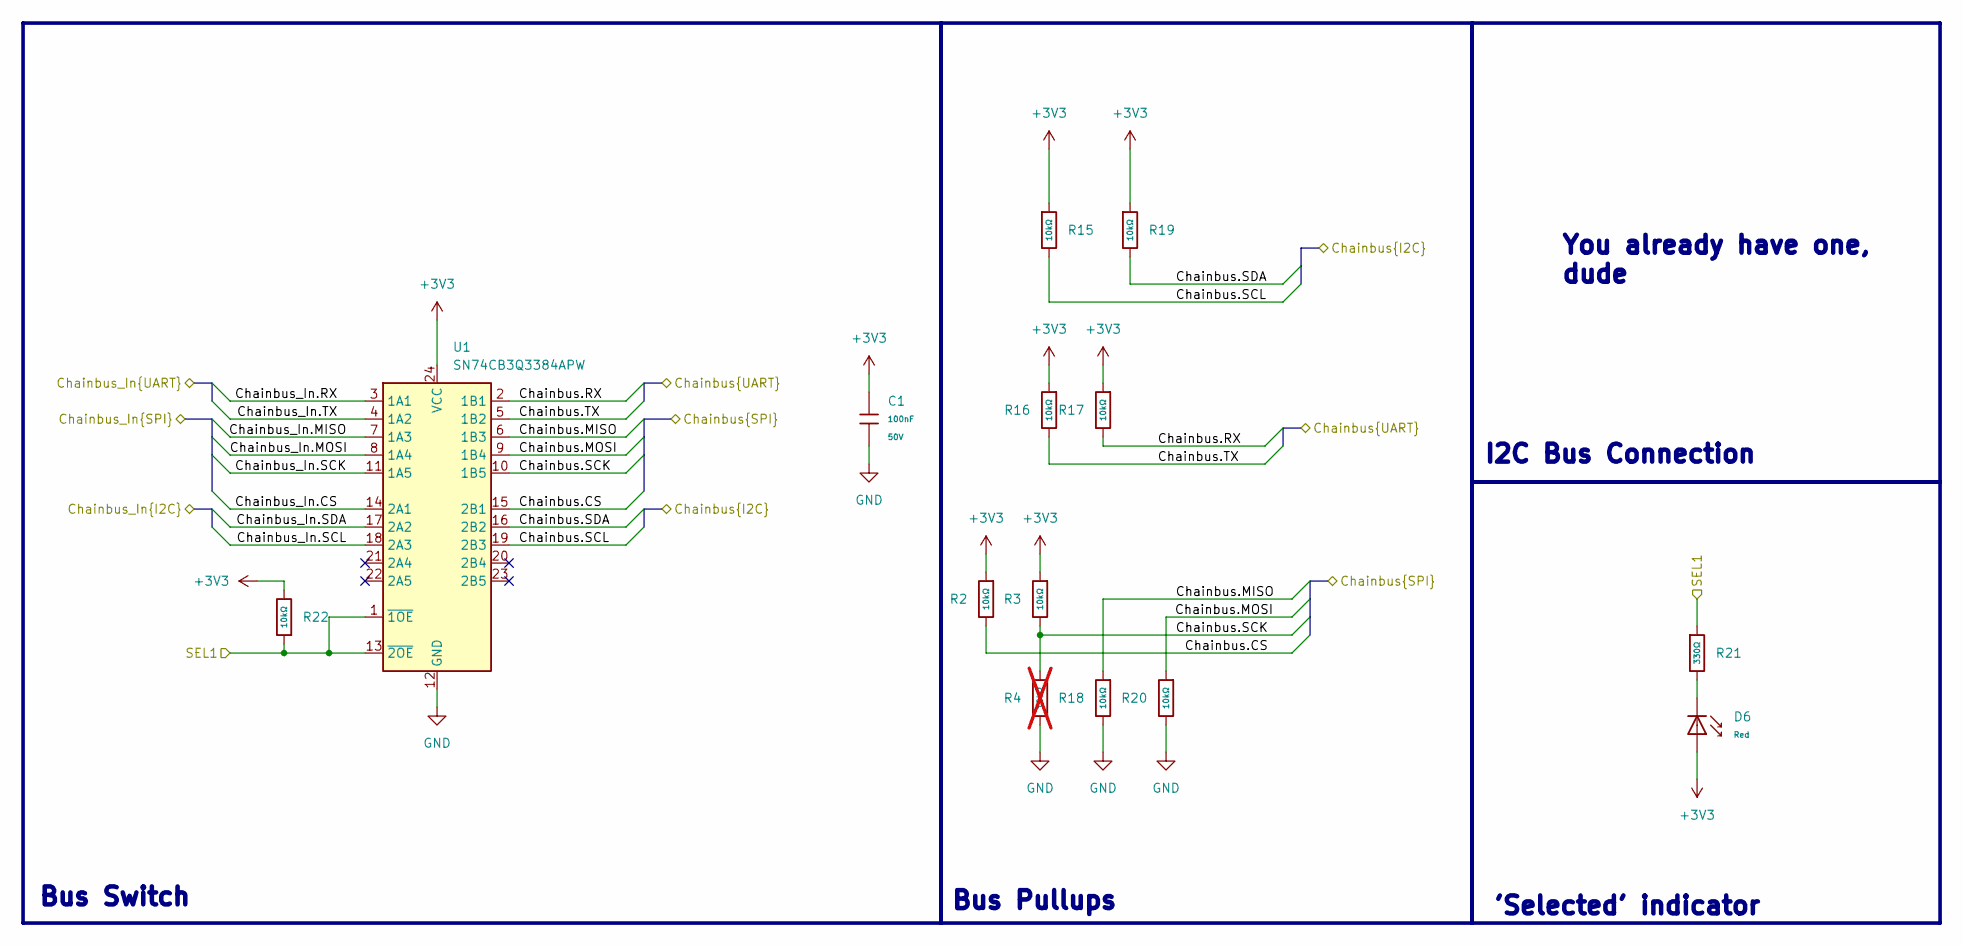
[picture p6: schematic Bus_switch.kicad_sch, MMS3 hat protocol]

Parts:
C1: 100nF; C_0603; Voltage Rated 50V; Tolerance ±10%; Part CC0603KRX7R9BB104; LCSC C14663
D6: Red; D_0603; Part KT-0603R; LCSC C2286
R2, R3, R15, R16, R17, R18, R19, R20, R22: 10kΩ; R_0402; Overload Voltage (Max) 50V; Tolerance ±1%; Part 0402WGF1002TCE; LCSC C25744
R4: 10kΩ; R_0402; Overload Voltage (Max) 50V; Tolerance ±1%; Part 0402WGF1002TCE; LCSC C25744; not fitted
R21: 330Ω; R_0402; Overload Voltage (Max) 50V; Tolerance ±1%; Part 0402WGF3300TCE; LCSC C25104
U1: SN74CB3Q3384APW; TSSOP-24_4.4x7.8mm_P0.65mm; LCSC C469874

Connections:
+3V3: C1.1, D6.2, R2.1, R3.1, R15.1, R16.1, R17.1, R19.1, R22.2, U1.24 (VCC); also elsewhere on the board
/Bus_switch/Chainbus_In.CS: U1.14 (2A1); also elsewhere on the board
/Bus_switch/Chainbus_In.MISO: U1.7 (1A3); also elsewhere on the board
/Bus_switch/Chainbus_In.MOSI: U1.8 (1A4); also elsewhere on the board
/Bus_switch/Chainbus_In.RX: U1.3 (1A1); also elsewhere on the board
/Bus_switch/Chainbus_In.SCK: U1.11 (1A5); also elsewhere on the board
/Bus_switch/Chainbus_In.SCL: U1.18 (2A3); also elsewhere on the board
/Bus_switch/Chainbus_In.SDA: U1.17 (2A2); also elsewhere on the board
/Bus_switch/Chainbus_In.TX: U1.4 (1A2); also elsewhere on the board
/Bus_switch/SEL1: R21.1, R22.1, U1.1 (~1OE), U1.13 (~2OE); also elsewhere on the board
/Chainbus.CS: R2.2, U1.15 (2B1); also elsewhere on the board
/Chainbus.MISO: R18.1, U1.6 (1B3); also elsewhere on the board
/Chainbus.MOSI: R20.1, U1.9 (1B4); also elsewhere on the board
/Chainbus.RX: R17.2, U1.2 (1B1); also elsewhere on the board
/Chainbus.SCK: R3.2, R4.1, U1.10 (1B5); also elsewhere on the board
/Chainbus.SCL: R15.2, U1.19 (2B3); also elsewhere on the board
/Chainbus.SDA: R19.2, U1.16 (2B2); also elsewhere on the board
/Chainbus.TX: R16.2, U1.5 (1B2); also elsewhere on the board
GND: C1.2, R4.2, R18.2, R20.2, U1.12 (GND); also elsewhere on the board
unnamed: D6.1, R21.2

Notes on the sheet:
Bus Switch
Bus Pullups
You already have one, dude
'Selected' indicator
I2C Bus Connection

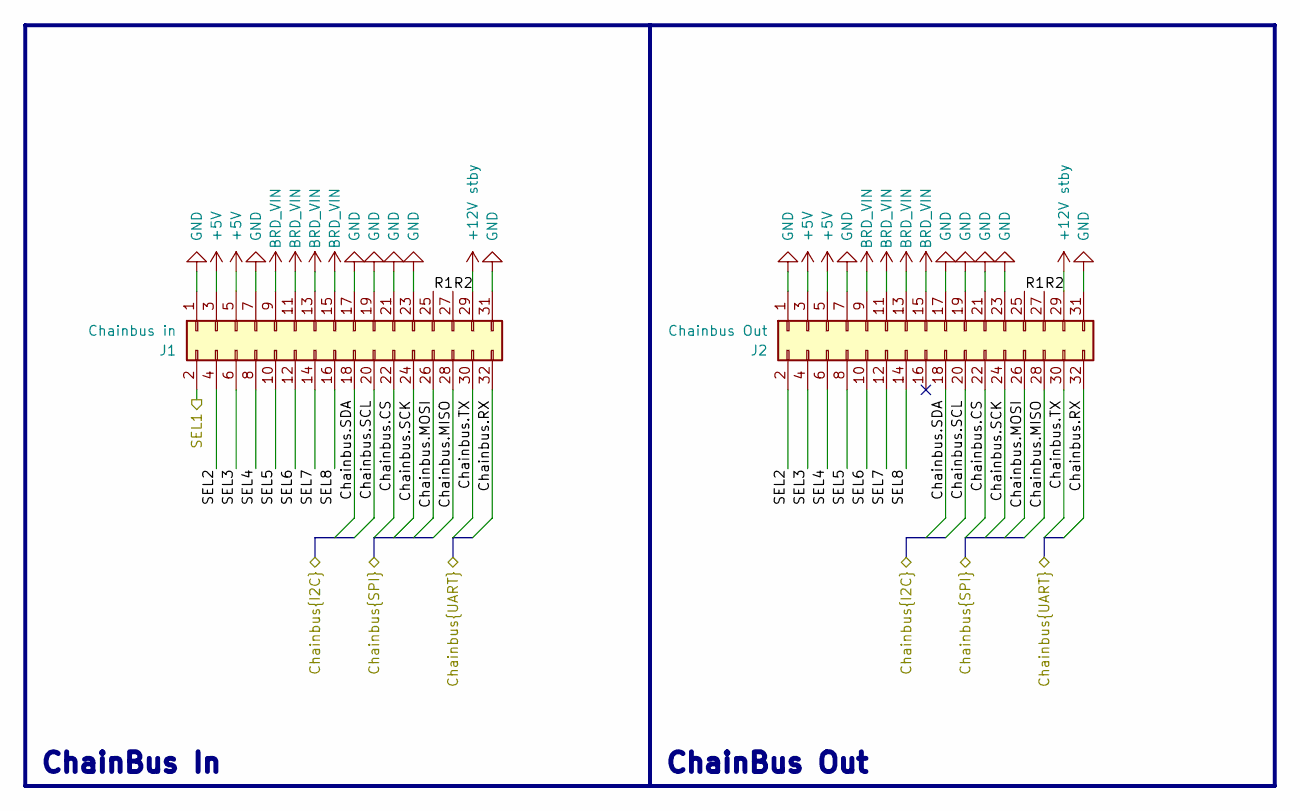
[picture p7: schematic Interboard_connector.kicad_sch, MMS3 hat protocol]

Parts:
J1: Chainbus in; PinHeader_2x16_P2.54mm_Vertical_SMD
J2: Chainbus Out; PinSocket_2x16_P2.54mm_Vertical_SMD

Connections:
+5V: J1.3, J1.5, J2.3, J2.5; also elsewhere on the board
+12V stby: J1.29, J2.29
/Bus_switch/Chainbus_In.CS: J1.22, J2.22; also elsewhere on the board
/Bus_switch/Chainbus_In.MISO: J1.28, J2.28; also elsewhere on the board
/Bus_switch/Chainbus_In.MOSI: J1.26, J2.26; also elsewhere on the board
/Bus_switch/Chainbus_In.RX: J1.32, J2.32; also elsewhere on the board
/Bus_switch/Chainbus_In.SCK: J1.24, J2.24; also elsewhere on the board
/Bus_switch/Chainbus_In.SCL: J1.20, J2.20; also elsewhere on the board
/Bus_switch/Chainbus_In.SDA: J1.18, J2.18; also elsewhere on the board
/Bus_switch/Chainbus_In.TX: J1.30, J2.30; also elsewhere on the board
/Bus_switch/SEL1: J1.2; also elsewhere on the board
/Interboard_connector/R1: J1.25, J2.25
/Interboard_connector/R2: J1.27, J2.27
/Interboard_connector/SEL2: J1.4, J2.2
/Interboard_connector/SEL3: J1.6, J2.4
/Interboard_connector/SEL4: J1.8, J2.6
/Interboard_connector/SEL5: J1.10, J2.8
/Interboard_connector/SEL6: J1.12, J2.10
/Interboard_connector/SEL7: J1.14, J2.12
/Interboard_connector/SEL8: J1.16, J2.14
BRD_VIN: J1.9, J1.11, J1.13, J1.15, J2.9, J2.11, J2.13, J2.15
GND: J1.1, J1.7, J1.17, J1.19, J1.21, J1.23, J1.31, J2.1, J2.7, J2.17, J2.19, J2.21, J2.23, J2.31; also elsewhere on the board

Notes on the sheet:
ChainBus In
ChainBus Out

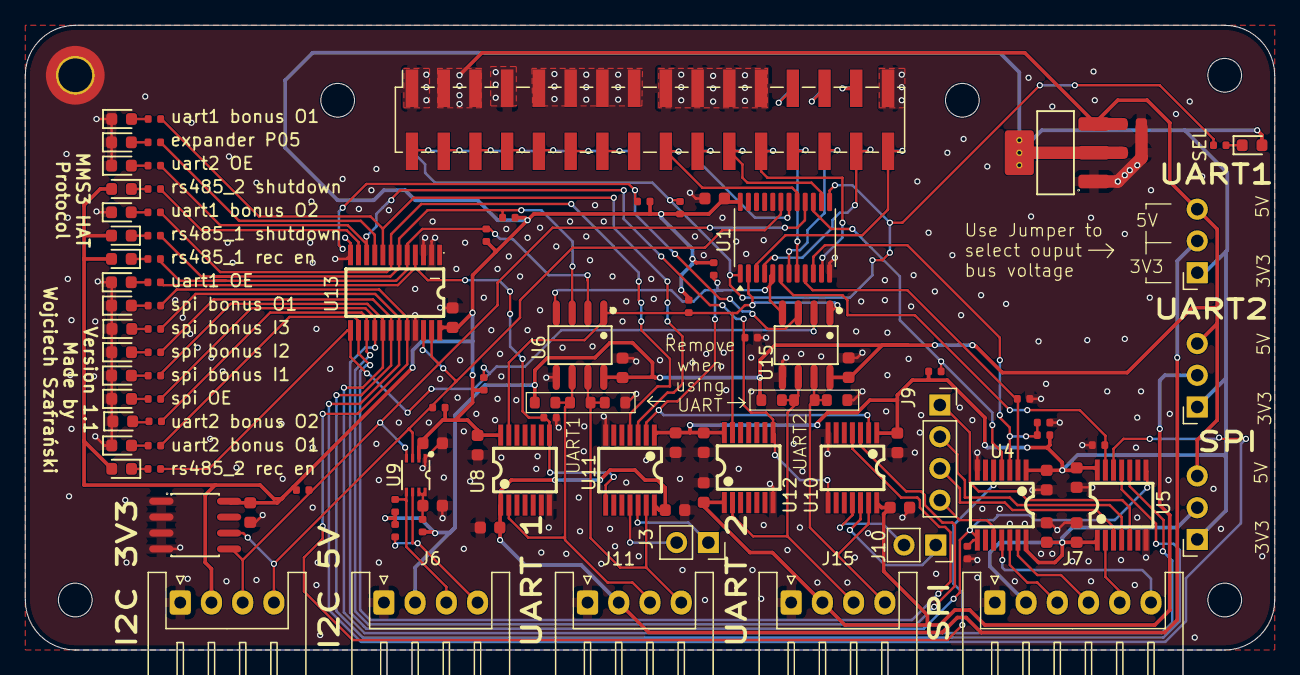
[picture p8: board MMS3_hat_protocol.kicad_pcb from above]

Board: 2 copper layers, 100.0 x 50.0 mm, 113 parts (1 on the bottom side), 86 nets.

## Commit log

2026-03-05 some schematic done
    [Bus_switch.kicad_sch, ID_EEPROM.kicad_sch, Interboard_connector.kicad_sch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]
2026-04-18 finished schematic
    [Bus_switch.kicad_sch, ID_EEPROM.kicad_sch, Interboard_connector.kicad_sch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]
2026-04-20 generated final bom
    [BOM-MMS3_hat_protocol.csv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]
2026-06-09 added documentation
    [BOM-MMS3_hat_protocol.csv, Bus_switch.kicad_sch, ID_EEPROM.kicad_sch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]
2026-08-14 V1.1, added photo
    [BOM-MMS3_hat_protocol.csv, Bus_switch.kicad_sch, ID_EEPROM.kicad_sch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]
2026-08-14 fixed reserved pins
    [Interboard_connector.kicad_sch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]
